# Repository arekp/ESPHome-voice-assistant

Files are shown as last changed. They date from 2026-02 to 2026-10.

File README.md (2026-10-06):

# ESPHome Voice Assistant

Asystent głosowy oparty na ESP32-S3 N16R8 z lokalnym wykrywaniem słowa budzącego dla integracji z Home Assistant.

## Opis

Ten projekt dostarcza kompletną konfigurację ESPHome do budowy asystenta głosowego używającego ESP32-S3 z lokalnym wykrywaniem słowa budzącego. System bezproblemowo integruje się z Home Assistant do sterowania inteligentnym domem.

## 🛠️ Wymagany Sprzęt
1. **ESP32-S3 DevKitC-1** (Zalecana wersja N16R8 lub N8R8)
2. **Wyświetlacz:** 1.28" Round IPS LCD (Sterownik GC9A01)
3. **Mikrofon:** INMP441 (I2S, dookólny)
4. **Wzmacniacz/DAC:** MAX98357A (I2S, 3W)
5. Głośnik: 4Ω 3W

## 🔌 Schemat Połączeń (Pinout)

### ✅ Aktualne okablowanie (zgodne z `esp_ver2.yaml`, przetestowane)

Schemat połączeń: ESP32-S3 DevKitC-1, INMP441, MAX98357A, GC9A01

| Moduł | Sygnał → GPIO | Zasilanie |
| :--- | :--- | :--- |
| Mikrofon INMP441 (sekcja 1_v5) | WS→4, SCK→5, SD→6, L/R→GND | 3V3 |
| Wzmacniacz MAX98357A (sekcja 2_1) | LRC→7, BCLK→8, DIN→18 | **3V3** (tymczasowo, patrz niżej) |
| Wyświetlacz GC9A01 (sekcja 3) | DC→9, CS→10, SDA→11, SCL→12, RES→13, BLK→14 | 3V3 |

⚠️ **Pin 5V na klonach ESP32-S3 N16R8 może nie mieć napięcia.** Obok pinu jest zworka
lutownicza **IN-OUT** – dopóki nie jest zlutowana, pin 5V nie dostaje zasilania z USB i
wzmacniacz milczy (firmware „gra”, ale nic nie słychać). Obecnie MAX98357A jest zasilany z 3V3
(działa, ciszej). Docelowo: zlutować IN-OUT i przepiąć Vin na 5V.

Pozostałe tabele poniżej to historia testowanych wariantów pinów.

Poniższa tabela przedstawia bezpieczne połączenia dla **ESP32-S3 DevKitC-1**, które nie kolidują z pamięcią Flash/PSRAM oraz wbudowanymi funkcjami.

### 1. Mikrofon (INMP441)
⚠️ Krytyczne ostrzeżenie o pinach
W układach ESP32-S3 z Octal PSRAM (N16R8), piny od GPIO 33 do GPIO 37 oraz GPIO 40, 41 i 42 są wykorzystywane wewnętrznie do komunikacji z pamięcią RAM i Flash.
| Pin INMP441 | Pin ESP32-S3 | Uwagi |
| :--- | :--- | :--- |
| **VDD** | **3.3V** | ⚠️ Podłączenie pod 5V uszkodzi mikrofon! |
| **GND** | GND | |
| **L/R** | GND | Wybór kanału Lewego |
| **WS** | GPIO 40 | Word Select |
| **SCK** | GPIO 41 | Zegar |
| **SD** | GPIO 42 | Dane wyjściowe |

### 1_v2. Mikrofon (INMP441) _V2 dla plytki ver MON16R8
| Pin INMP441 | Pin ESP32-S3 | Uwagi |
| :--- | :--- | :--- |
| **VDD** | **3.3V** | ⚠️ Podłączenie pod 5V uszkodzi mikrofon! |
| **GND** | GND | |
| **L/R** | GND | Wybór kanału Lewego |
| **WS** | GPIO 15 | Word Select |
| **SCK** | GPIO 16 | Zegar |
| **SD** | GPIO 17 | Dane wyjściowe |

### 1_v3. Mikrofon (INMP441) _V3 dla plytki ver MON16R8
Zmień piny magistrali wejściowej (mikrofonu): Piny 36 i 37 na S3 z 8MB PSRAM prawie na pewno kolidują z pamięcią. Spróbuj użyć pinów, które nie należą do zakresu 33-37.
| Pin INMP441 | Pin ESP32-S3 | Uwagi |
| :--- | :--- | :--- |
| **VDD** | **3.3V** | ⚠️ Podłączenie pod 5V uszkodzi mikrofon! |
| **GND** | GND | |
| **L/R** | GND | Wybór kanału Lewego |
| **WS** | GPIO 36 | Word Select |
| **SCK** | GPIO 37 | Zegar |
| **SD** | GPIO 39 | Dane wyjściowe |

### 1_v4. Mikrofon (INMP441) _V3 dla plytki ver MON16R8 - do opracowania 

| Pin INMP441 | Pin ESP32-S3 | Uwagi |
| :--- | :--- | :--- |
| **VDD** | **3.3V** | ⚠️ Podłączenie pod 5V uszkodzi mikrofon! |
| **GND** | GND | |
| **L/R** | GND | Wybór kanału Lewego |
| **WS** | GPIO3  | Word Select |
| **SCK** | GPIO2  | Zegar |
| **SD** | GPIO1  | Dane wyjściowe |

### 1_v5. Mikrofon (INMP441) _V3 dla plytki ver MON16R8 - do opracowania 

| Pin INMP441 | Pin ESP32-S3 | Uwagi |
| :--- | :--- | :--- |
| **VDD** | **3.3V** | ⚠️ Podłączenie pod 5V uszkodzi mikrofon! |
| **GND** | GND | |
| **L/R** | GND | Wybór kanału Lewego |
| **WS** | GPIO4  | Word Select |
| **SCK** | GPIO5  | Zegar |
| **SD** | GPIO6 | Dane wyjściowe |

----
### 2. Głośnik (MAX98357A)
| Pin MAX98357A | Pin ESP32-S3 | Uwagi |
| :--- | :--- | :--- |
| **Vin** | **5V (VBUS)** | Zalecane 5V dla lepszej jakości dźwięku |
| **GND** | GND | Wspólna masa |
| **LRC** | GPIO 4 | Word Select |
| **BCLK** | GPIO 5 | Bit Clock |
| **DIN** | GPIO 6 | Dane wejściowe |

### 2_1. Głośnik (MAX98357A)
| Pin MAX98357A | Pin ESP32-S3 | Uwagi |
| :--- | :--- | :--- |
| **Vin** | **5V (VBUS)** | Zalecane 5V dla lepszej jakości dźwięku |
| **GND** | GND | Wspólna masa |
| **LRC** | GPIO 7 | Word Select |
| **BCLK** | GPIO 8 | Bit Clock |
| **DIN** | GPIO 18 | Dane wejściowe |

### 3. Wyświetlacz (GC9A01)
| Pin GC9A01 | Pin ESP32-S3 | Funkcja |
| :--- | :--- | :--- |
| **VCC** | 3.3V | Zasilanie |
| **GND** | GND | Masa |
| **DC** | GPIO 9 | Data/Command |
| **CS** | GPIO 10 | Chip Select |
| **SDA** | GPIO 11 | SPI MOSI |
| **SCL** | GPIO 12 | SPI Clock |
| **RES** | GPIO 13 | Reset |
| **BLK** | GPIO 14 | Podświetlenie (PWM) |

---

## Konfiguracja Oprogramowania

Upewnij się, że w Twoim pliku `.yaml` sekcje `i2s_audio` i `display` korzystają z powyższych pinów.

### Dlaczego takie piny?
1.  **Piny 4-8 i 18 (Audio):** Nie kolidują z Octal PSRAM (GPIO 33-37) ani z pinami bootowania (GPIO 0, 3, 45, 46). Mikrofon i głośnik mają osobne magistrale I2S.
2.  **Piny 9-14 (SPI):** Są zgrupowane fizycznie blisko siebie na DevKicie, co ułatwia prowadzenie przewodów, i nie kolidują z pamięcią Octal SPI Flash/PSRAM (która zajmuje piny 26-32).
3.  **MAX98357A:** Ten układ automatycznie miksuje kanał lewy i prawy do mono, jeśli pin SD jest niepodłączony, co jest idealne dla prostego asystenta głosowego.

### 1. Konfiguracja Home Assistant

Zainstaluj wymagane dodatki Home Assistant:
- **Whisper** - Zamiana mowy na tekst
- **Piper** - Zamiana tekstu na mowę
- **Voice Assist** - Potok głosowy

W **Ustawienia → Asystenci głosowi** asystent używany przez urządzenie musi mieć istniejącego
agenta konwersacji (np. `OpenAI Conversation` albo `Home Assistant`), STT (Whisper) i TTS (Piper).
Nieistniejący agent powoduje natychmiastowy błąd `intent-not-supported` po słowie budzącym.

### 2. Konfiguracja ESPHome

Główny plik to `esp_ver2.yaml`. Sekrety (WiFi, klucz API, hasło OTA) trzymamy w `.env`
(wzór: `.env.example`), z którego `scripts/env2secrets.py` generuje `secrets.yaml`.

### 🚀3. Flashowanie i development

Pełna instrukcja budowy środowiska, kompilacji, wgrywania (kablem i przez WiFi) oraz
diagnostyki: **[docs/DEVELOPMENT.md](docs/DEVELOPMENT.md)**. W skrócie:

```bash
scripts/deploy.sh COM4                    # pierwszy raz kablem
scripts/deploy.sh voice-assistant.local   # potem przez WiFi
```

## Funkcje

- **Lokalne Wykrywanie Słowa Budzącego**: "Okay Nabu" przy użyciu Micro Wake Word (aktywne, gdy HA jest połączony)
- **Animowana twarz robota** (oczy-pastylki w stylu EMO/Cozmo): naturalne mruganie, rozglądanie się, płynne zmiany kształtu; pod oczami wskaźnik stanu – słupki przy słuchaniu, skaczące kropki przy myśleniu, usta przy mówieniu. Rysowane są tylko zmienione fragmenty ekranu, więc animacja nie obciąża ESP
- **Limit nasłuchu**: bez mowy przez 8 s asystent wraca do czuwania (także po pytaniu zwrotnym asystenta)
- **Wygaszacz „Matrix”**: po 3 min bezczynności zielony deszcz znaków zamiast oczu; czas ustawiasz w HA (encja „Wygaszacz Matrix po”, 0 = wyłączony), przycisk „Test wygaszacza Matrix”
- **Przyciski testowe**: Test RTTTL (dźwięk), Test wygaszacza Matrix, Wymuś Nasłuch, Restart
- **OTA Updates**: Aktualizacje oprogramowania przez sieć
- **Redukcja Szumów i auto-gain** mikrofonu

## Użycie

1. Powiedz "Okay Nabu" aby aktywować
2. Oczy robią się **zielone**, pod nimi pulsują słupki – mów polecenie
3. **Żółte**, zmrużone oczy i skaczące kropki – asystent myśli
4. **Niebieskie** oczy z ustami – asystent odpowiada z głośnika
5. Powrót do białych, mrugających i rozglądających się oczu

## Szczegóły Konfiguracji

### Ustawienia Audio
```yaml
bits_per_sample: 32bit
 sample_rate: 16000
 noise_suppression_level: 2.0
 volume_multiplier: 4.0
```

## Integracja

Asystent integruje się z encjami Home Assistant dla:
- Sterowania oświetleniem
- Sterowania przełącznikami
- Odtwarzania mediów
- Własnych skryptów

## Rozwiązywanie Problemów

### Częste Problemy
- **Brak wyjścia audio** (a w logach `rtttl: Playing song` / `i2s_audio.speaker: Starting`):
  brak napięcia na pinie 5V – zlutuj zworkę IN-OUT albo zasil MAX98357A z 3V3.
  Test: `scripts/button.py RTTTL` powinien dać dwa piknięcia.
- **Oczy nie zmieniają się po "Okay Nabu"**: sprawdź logi – jeśli jest `intent-not-supported`,
  asystent w HA ma ustawionego nieistniejącego agenta konwersacji.
- **Słowo budzące w ogóle nie działa**: wykrywanie startuje dopiero po połączeniu z Home Assistant.

Pełna lista rozwiązanych problemów: [docs/DEVELOPMENT.md](docs/DEVELOPMENT.md#7-rozwiązane-problemy-październik-2026).

### Tryb Debug
Logi przez WiFi: `esphome logs esp_ver2.yaml --device voice-assistant.local`
(albo kablem na COM4 – logger działa na `UART0`).

## Zasoby

- [Dokumentacja ESPHome](https://esphome.io/)
- [Micro Wake Word](https://github.com/kahrendt/microWakeWord)
- [Home Assistant Voice](https://www.home-assistant.io/blog/2023/12/13/year-of-the-voice-chapter-5/)
- [film prezentujacy asystenata](https://youtu.be/aDaSp6zaqWM?is=lCuZWlRpG83gZBLt)
- [Dokumentacja wyswietlacza](https://sklep.msalamon.pl/produkt/okragly-wyswietlacz-tft-ips-128-niebiesk/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)
- [kolejny przyklad implementacji](https://www.instructables.com/DIY-Pocket-Size-ESP32-AI-Voice-Assistant-With-Xiao/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)
- [Pobieranie slow wybudzenia](https://github.com/esphome/micro-wake-word-models/blob/main/models/v2/hey_jarvis.json)

## Licencja

Licencja MIT - Szczegóły w pliku LICENSE.

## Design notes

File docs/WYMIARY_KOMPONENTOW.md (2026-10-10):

# Wymiary komponentów elektronicznych

Wymiary w mm. ✅ – potwierdzone (rysunek producenta / sprzedawca), ⚠️ – przybliżone, ❌ – brak danych.

| # | Komponent | Wymiary modułu | Szczegóły | Pewność |
|---|---|---|---|---|
| 1 | **ESP32-S3 N16R8** – klon YD-ESP32-S3 (VCC-GND), 2× USB-C, CH343 | PCB **57,15 × 27,94 × 1,6**; z wystającym modułem WROOM (antena) **63,39** długości | 2 rzędy po 22 piny, raster 2,54, rozstaw rzędów **25,40**; moduł WROOM ok. 3,3 nad PCB, elementy nad PCB do ok. 4,5 | ✅ |
| 1a | Gniazda USB-C płytki | gniazdo ok. 9 × 3,2 | na krótszym brzegu (naprzeciw anteny), środki **8,1** i **19,8** mm od krawędzi płytki | ✅ |
| 2 | **Wyświetlacz okrągły 1,28" GC9A01** (msalamon) | **38 × 45,5 × 11,5** (z goldpinami) | obszar pikseli **Ø32,4**; szkło ok. Ø35,6; 8 wyprowadzeń | ✅ / szkło ⚠️ |
| 3 | **Mikrofon INMP441** (moduł I2S) | PCB ok. **14 × 14** (wersje okrągłe Ø15), gr. ok. 3 | port akustyczny – otwór w PCB | ⚠️ |
| 4 | **Wzmacniacz MAX98357A** (moduł I2S, 3 W) | **19,4 × 17,8 × 3** (klony ok. 18 × 18) | 7 pinów + złącze głośnika | ⚠️ |
| 5 | **Głośnik 4 Ω / 3 W** | ramka **63 × 63**, głębokość **12** | membrana (kosz) **Ø45** pośrodku ramki | ✅ (zmierzone) |

Wtyki dupont nałożone na goldpiny wystają ok. 14–17 mm od PCB.

## Do zmierzenia
1. Szkło wyświetlacza (średnica) i po której stronie modułu są piny.
2. Moduł INMP441: kształt (kwadrat / koło), położenie otworu akustycznego.
3. Klon MAX98357A: wymiary i czy ma złącze śrubowe głośnika.
4. Otwory montażowe modułów (średnica, położenie) – brak danych.

## Źródła
- [YD-ESP32-S3 – rysunek wymiarowy (vcc-gnd)](https://github.com/vcc-gnd/YD-ESP32-S3/tree/main/5-public-YD-ESP32-S3-Hardware%20info)
- [Wyświetlacz GC9A01 1,28" – msalamon](https://sklep.msalamon.pl/produkt/okragly-wyswietlacz-tft-ips-128-niebiesk/)
- [Waveshare 1.28inch LCD Module](https://www.waveshare.com/1.28inch-lcd-module.htm)
- [Adafruit MAX98357A](https://www.adafruit.com/product/3006)
- [INMP441 – TinyTronics](https://www.tinytronics.nl/en/sensors/sound/inmp441-mems-microphone-i2s)
- [INMP441 – datasheet (port akustyczny)](https://www.mouser.com/datasheet/2/400/INMP441-1112508.pdf)

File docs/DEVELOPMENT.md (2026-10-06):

# Środowisko developerskie

Instrukcja przygotowania komputera (Windows 11) do kompilowania, wgrywania i diagnozowania
firmware asystenta głosowego. Na Linux/macOS kroki są te same, zmieniają się tylko ścieżki
(`.venv/bin` zamiast `.venv/Scripts`, port `/dev/ttyUSB0` zamiast `COM4`).

## 1. Wymagania

| Element | Wersja / uwagi |
| :--- | :--- |
| Python | **3.12 lub nowszy** (zalecany 3.13). ESPHome 2026.9+ nie działa na 3.11 |
| ESPHome | **taka sama wersja jak dodatek ESPHome w Home Assistant** (obecnie 2026.9.1) |
| Git + Git Bash | do `scripts/deploy.sh` |
| Sterownik CH343 | gniazdo „UART” płytki widoczne jako `USB-Enhanced-SERIAL CH343 (COMx)` |
| Miejsce na dysku | ~3 GB na ESP-IDF i toolchain |

Python 3.13 bez uprawnień administratora:

```powershell
winget install --id Python.Python.3.13 --scope user
```

## 2. Środowisko Python (`.venv`)

```powershell
cd C:\Projekty\ESPHome-voice-assistant
py -3.13 -m venv .venv
.\.venv\Scripts\python.exe -m pip install --upgrade pip
.\.venv\Scripts\python.exe -m pip install -r requirements.txt
.\.venv\Scripts\esphome.exe version     # powinno pokazać 2026.9.1
```

Venv na Windows nie da się przenieść ani zmienić mu nazwy (pliki `.exe` mają zaszyte ścieżki).
Przy zmianie wersji Pythona usuń `.venv` i utwórz go od nowa.

## 3. Windows: limit długości ścieżek

ESP-IDF tworzy ścieżki dłuższe niż 260 znaków. Przy wyłączonych długich ścieżkach
(`LongPathsEnabled = 0`) kompilacja kończy się błędami typu
`fatal error: bits/c++config.h: No such file or directory` albo `WinError 206`.

Rozwiązanie bez uprawnień administratora: narzędzia ESP-IDF w krótkiej ścieżce.

```powershell
New-Item -ItemType Directory -Force C:\ESPHome\idf
[Environment]::SetEnvironmentVariable('ESPHOME_ESP_IDF_PREFIX', 'C:\ESPHome\idf', 'User')
```

(`scripts/deploy.sh` ustawia tę zmienną sam). Alternatywa: włączyć długie ścieżki w rejestrze
(PowerShell jako administrator) i zrestartować komputer:

```powershell
Set-ItemProperty 'HKLM:\SYSTEM\CurrentControlSet\Control\FileSystem' LongPathsEnabled 1
```

Projekt trzymaj w krótkiej ścieżce (np. `C:\Projekty\...`), nie w `%TEMP%` ani głęboko w profilu.

## 4. Sekrety (`.env`)

```powershell
copy .env.example .env    # i uzupełnij wartości
```

| Zmienna | Opis |
| :--- | :--- |
| `WIFI_SSID`, `WIFI_PASSWORD` | sieć WiFi |
| `FALLBACK_AP_PASSWORD` | hasło zapasowego hotspotu (min. 8 znaków) |
| `API_KEY` | klucz szyfrowania API (base64, 32 bajty) – **ten sam, co zna HA** |
| `OTA_PASSWORD` | hasło OTA – **takie jak w firmware, który jest na płytce** |
| `HA_URL`, `HA_TOKEN` | opcjonalnie: adres HA i token długoterminowy (dla `scripts/ha.py`) |

ESPHome czyta sekrety tylko z `secrets.yaml` (`!secret`), więc `scripts/env2secrets.py`
generuje go z `.env`. Robi to automatycznie `scripts/deploy.sh`; ręcznie:

```powershell
.\.venv\Scripts\python.exe scripts\env2secrets.py
```

`.env` i `secrets.yaml` są w `.gitignore` – nigdy ich nie commituj.

## 5. Kompilacja, wgrywanie, logi

Pełny cykl (walidacja → kompilacja → wgranie → 60 s logów do `logs/`):

```bash
scripts/deploy.sh COM4                      # pierwszy raz kablem (gniazdo „UART”)
scripts/deploy.sh voice-assistant.local     # kolejne razy przez WiFi (OTA)
scripts/deploy.sh voice-assistant.local 0   # bez zbierania logów
SKIP_UPLOAD=1 scripts/deploy.sh             # tylko kompilacja
```

Pojedyncze kroki (PowerShell):

```powershell
$env:PYTHONUTF8 = '1'                       # polskie znaki w konsoli Windows
.\.venv\Scripts\esphome.exe config  esp_ver2.yaml
.\.venv\Scripts\esphome.exe compile esp_ver2.yaml
.\.venv\Scripts\esphome.exe upload  esp_ver2.yaml --device voice-assistant.local
.\.venv\Scripts\esphome.exe logs    esp_ver2.yaml --device voice-assistant.local
```

- Pierwsza kompilacja pobiera ESP-IDF i toolchain (~15–25 min), kolejne trwają kilka minut.
- `esphome logs` nie kończy się sam – w skryptach używaj `timeout 60 esphome logs ...`.
- W Git Bash ESP-IDF odmawia pracy („MSys/Mingw is not supported”), bo widzi zmienną `MSYSTEM`.
  Samo `unset MSYSTEM` nie pomaga – runtime MSYS dokleja ją każdemu programowi Windows.
  `deploy.sh` uruchamia więc esphome przez Pythona, który usuwa zmienną; ręcznie najprościej z PowerShell.
- `deploy.sh` ustawia `PYTHONUNBUFFERED=1` – bez tego `timeout` ucina `esphome logs` razem z niezapisanym buforem.
- Logger działa na `UART0`, więc logi widać na COM4 (gniazdo „UART”) i przez WiFi.
- Nie da się jednocześnie wgrywać i czytać logów przez ten sam port COM.

## 6. Narzędzia diagnostyczne

```powershell
# Przyciski urządzenia przez API ESPHome (bez HA)
.\.venv\Scripts\python.exe scripts\button.py            # lista
.\.venv\Scripts\python.exe scripts\button.py RTTTL      # test głośnika (dwa piknięcia)

# Komendy WebSocket do Home Assistant (wymaga HA_URL/HA_TOKEN w .env)
.\.venv\Scripts\python.exe scripts\ha.py '{\"type\":\"assist_pipeline/pipeline/list\"}'
.\.venv\Scripts\python.exe scripts\ha.py '{\"type\":\"conversation/process\",\"text\":\"Która godzina?\",\"language\":\"pl\"}'

# Odczyt informacji o chipie przez kabel
.\.venv\Scripts\python.exe -m esptool --port COM4 flash-id
```

W logach urządzenia szukaj `[E]` i `[W]`. Przebieg poprawnej rozmowy:
`Detected 'Okay Nabu'` → `STT started` → `Speech recognised as: ...` → `Response: ...`
→ `TTS stream start` → `i2s_audio.speaker: Starting`.

## 7. Rozwiązane problemy (październik 2026)

| Objaw | Przyczyna | Rozwiązanie |
| :--- | :--- | :--- |
| YAML nie parsował się | dwie konfiguracje sklejone w jednym pliku | jedna spójna `esp_ver2.yaml`, sekrety przez `!secret` |
| Brak reakcji mikrofonu | w YAML piny 1/2/3, mikrofon podpięty do 4/5/6 | mikrofon na GPIO4/5/6 (README 1_v5) |
| Brak logów na COM4 | logger na `USB_SERIAL_JTAG`, kabel w gnieździe „UART” | `logger: hardware_uart: UART0` |
| Kompilacja: `WinError 206`, `c++config.h` | limit 260 znaków ścieżki w Windows | `ESPHOME_ESP_IDF_PREFIX=C:\ESPHome\idf` |
| Kompilacja: „MSys/Mingw is not supported” | uruchomienie z Git Bash (MSYS dokleja `MSYSTEM`) | esphome przez Pythona usuwającego zmienną / PowerShell |
| Puste logi w `deploy.sh` | `timeout` ubijał esphome przed zapisem bufora | `PYTHONUNBUFFERED=1` |
| Czarny ekran, oczy widoczne tylko w ruchu | `auto_clear_enabled` (domyślnie włączone) czyści bufor przed lambdą, a lambda pomija rysowanie bez zmian | `auto_clear_enabled: false` – lambda sama wymazuje zmienione fragmenty |
| Zrywająca się mowa, `Cannot receive audio, buffer is full` | animacja 20 kl./s blokowała pętlę główną; zmiana ust przerysowywała też oczy (duży prostokąt SPI) | oczy i usta przerysowywane osobno, 10 kl./s przy słuchaniu/mówieniu, `buffer_duration: 1000ms` |
| Asystent bez końca w trybie słuchania | HA wznawia rozmowę, gdy odpowiedź LLM kończy się pytaniem | skrypt `listen_timeout`: 8 s bez mowy → `voice_assistant.stop` |
| OTA: `connecting ... timed out` przy działającym API | zawieszona poprzednia sesja OTA | `scripts/button.py Restart` i ponowne wgranie |
| Lokalnie starsze ESPHome niż w HA | ESPHome 2026.9 wymaga Pythona ≥ 3.12 | `.venv` na Pythonie 3.13 |
| Słowo budzące „nie działa”, brak odpowiedzi | pipeline Assist „alfred” wskazywał nieistniejącego agenta `conversation.chatgpt` (HA zwracał błąd w ~20 ms, oczy mrugały na zielono niezauważalnie) | agent `conversation.openai_conversation` + „preferuj lokalne komendy” |
| Odpowiedź z innego głośnika (Atom Echo) | agent LLM użył narzędzia do wysłania komunikatu na inne urządzenie | to zachowanie LLM, nie firmware; Atom Echo odłączony |
| Cisza z głośnika (firmware odtwarza poprawnie) | pin 5V płytki bez napięcia – niezlutowana zworka **IN-OUT** na klonie N16R8 | tymczasowo Vin MAX98357A na **3V3**; docelowo zlutować IN-OUT i wrócić na 5V |

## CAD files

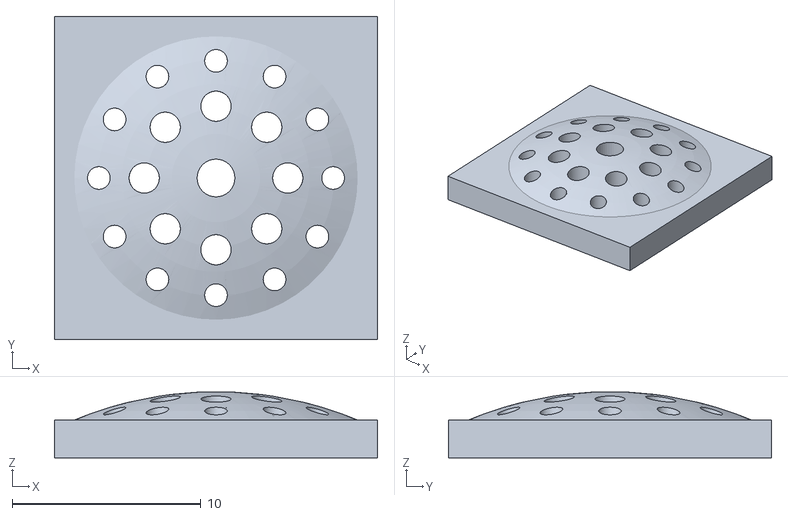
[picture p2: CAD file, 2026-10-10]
obudowa/do_druku/4_kratka_mikrofonu.stl
17.1 x 17.1 x 3.47

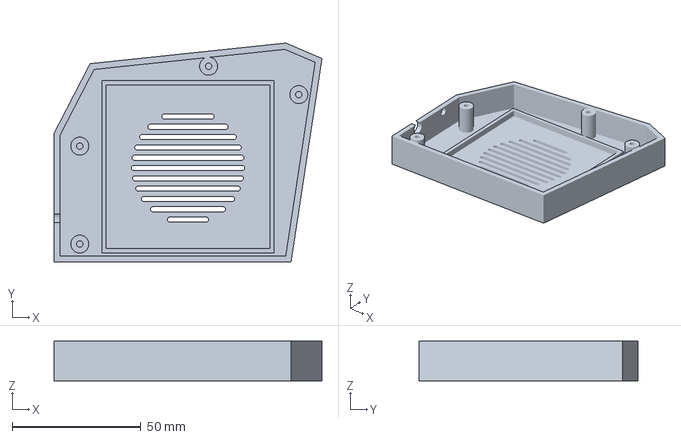
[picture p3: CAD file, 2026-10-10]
obudowa/statecznik_korpus.3mf
104.0 x 84.9 x 15.4 mm

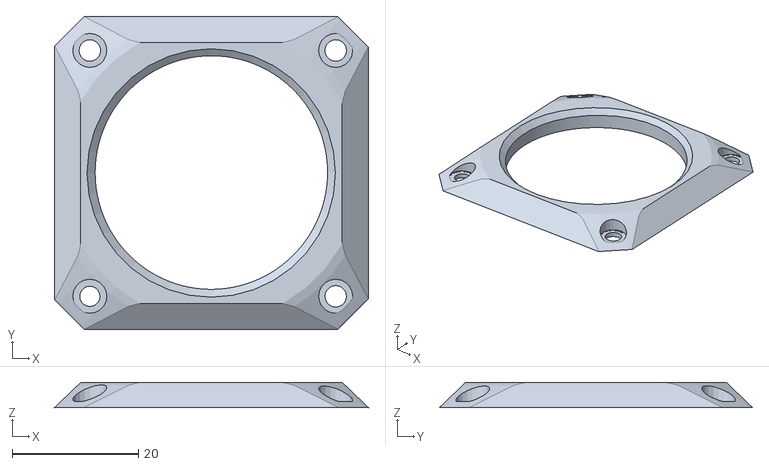
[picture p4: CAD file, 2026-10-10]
obudowa/szablon1/GC9A01_Round_OLED_Front_Contoured2.stl.stl
49.8 x 49.7 x 4.00

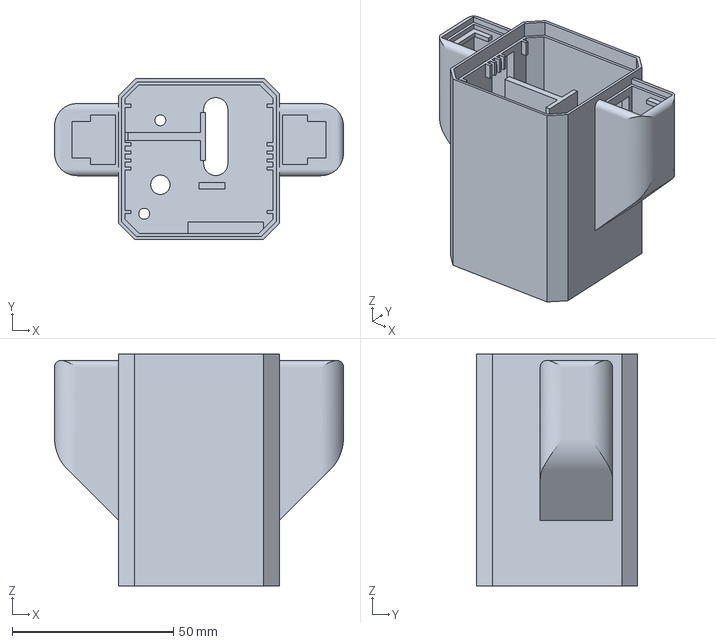
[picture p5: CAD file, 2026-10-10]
obudowa/do_druku/1_obudowa_esp32.3mf
89.7 x 49.9 x 72.0 mm

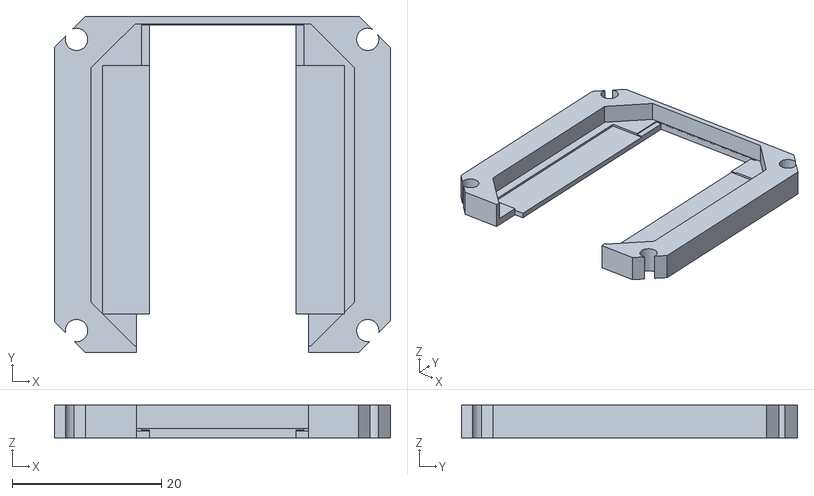
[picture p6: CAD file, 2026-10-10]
obudowa/szablon1/GC9A01_Round_OLED_Support.stl
45.0 x 45.0 x 4.40

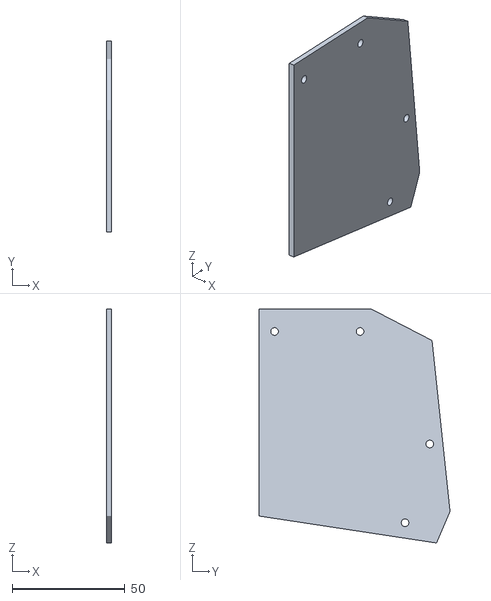
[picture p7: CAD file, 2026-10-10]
obudowa/do_druku/3_statecznik_pokrywa.stl
2.40 x 84.9 x 104.0

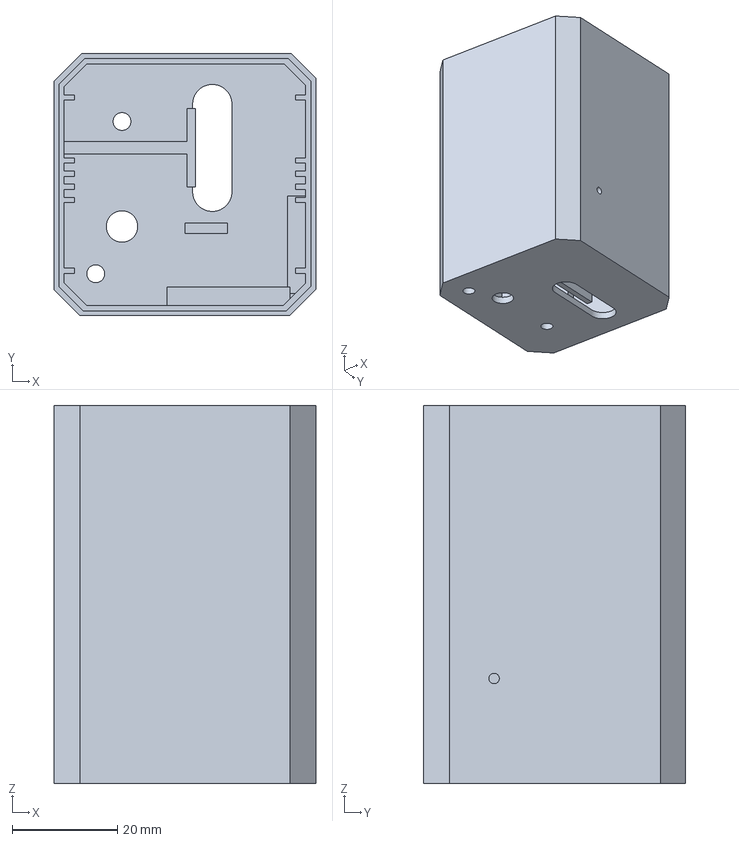
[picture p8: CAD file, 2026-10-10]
obudowa/obudowa_esp32.3mf
49.9 x 49.9 x 72.0 mm

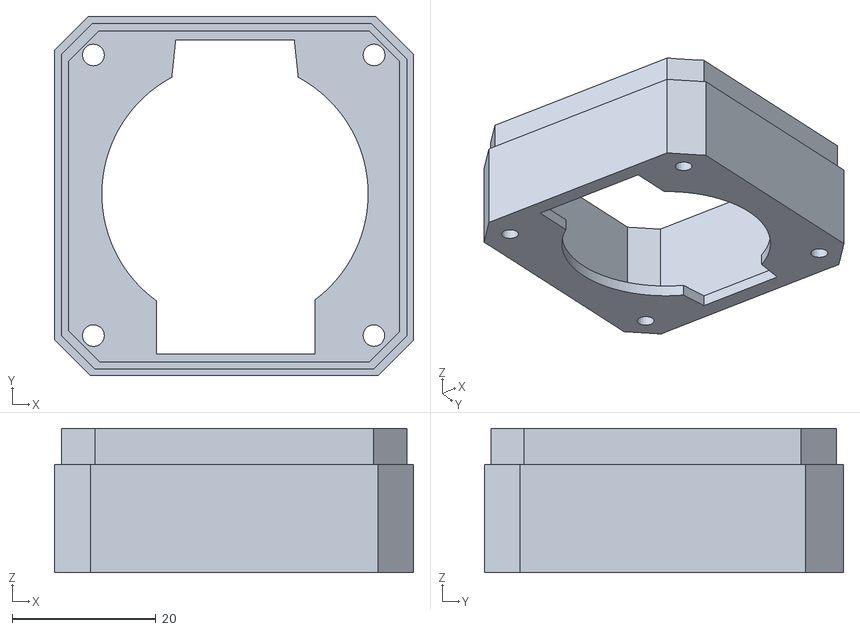
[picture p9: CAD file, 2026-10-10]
obudowa/szablon1/GC9A01_Round_OLED_Middle_notched.stl
49.9 x 49.9 x 20.0

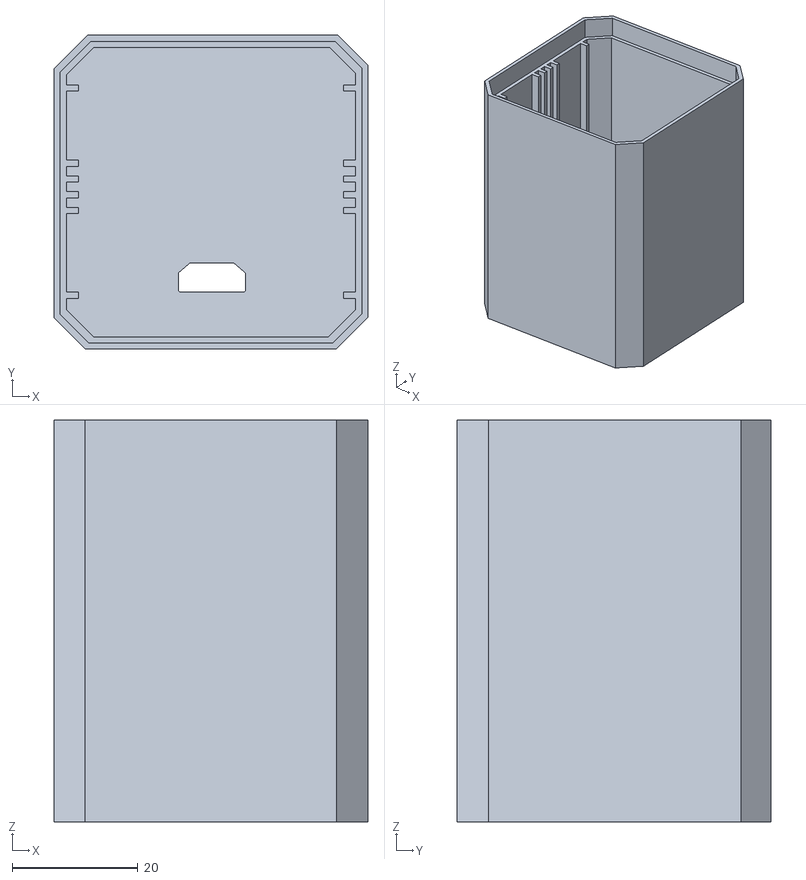
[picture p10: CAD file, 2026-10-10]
obudowa/szablon1/GC9A01_Round_OLED_Case_ribbed_usb.stl
49.9 x 49.9 x 64.0

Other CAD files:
obudowa/do_druku/2_statecznik_korpus.stl
obudowa/statecznik_pokrywa.3mf
obudowa/do_druku/1_obudowa_esp32.stl
obudowa/obudowa_esp32.stl
obudowa/statecznik_korpus.stl

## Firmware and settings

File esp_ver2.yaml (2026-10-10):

# Płytka: ESP32-S3 DevKitC-1 N16R8 (MON16R8)
# Piny zgodne z README: mikrofon sekcja 1_v5, głośnik sekcja 2_1, wyświetlacz sekcja 3.
esphome:
  name: voice-assistant
  friendly_name: voice-assistant
  on_boot:
    priority: -10
    then:
      - globals.set:
          id: va_state
          value: '0'
      # micro_wake_word startuje dopiero po połączeniu z Home Assistant
      # (voice_assistant -> on_client_connected)

esp32:
  board: esp32-s3-devkitc-1
  variant: esp32s3
  flash_size: 16MB
  framework:
    type: esp-idf
    sdkconfig_options:
      CONFIG_ESP32S3_DEFAULT_CPU_FREQ_240: y
      CONFIG_ESP32S3_DATA_CACHE_64KB: y
      CONFIG_ESP32S3_DATA_CACHE_LINE_64B: y

# Włączenie PSRAM - bez tego Wake Word nie zadziała!
psram:
  mode: octal
  speed: 80MHz

# Logi przez UART0 - płytka podłączona gniazdem "UART" (CH343, COM4)
logger:
  hardware_uart: UART0
  level: DEBUG # VERY_VERBOSE pokazuje wszystko, ale spowalnia ESP

# Enable Home Assistant API
api:
  encryption:
    key: !secret api_key

ota:
  - platform: esphome
    password: !secret ota_password

wifi:
  ssid: !secret wifi_ssid
  password: !secret wifi_password

  # Enable fallback hotspot (captive portal) in case wifi connection fails
  ap:
    ssid: "Voice-Assistant Fallback Hotspot"
    password: !secret fallback_ap_password

captive_portal:

# ---------------------------------------------------------
# STAN ASYSTENTA (Globalna zmienna dla wyświetlacza)
# 0 = Idle (Czuwanie/WakeWord), 1 = Listening (Nasłuch),
# 2 = Thinking (Przetwarzanie), 3 = Speaking (Mówienie)
# ---------------------------------------------------------
globals:
  - id: va_state
    type: int
    restore_value: no
    initial_value: '0'

  # Wygaszacz "Matrix": ostatnia aktywność asystenta (millis) i wymuszenie z przycisku
  - id: last_active_ms
    type: uint32_t
    restore_value: no
    initial_value: '0'
  - id: matrix_force
    type: bool
    restore_value: no
    initial_value: 'false'

# Bez mowy przez 8 s od otwarcia mikrofonu (np. po pytaniu zwrotnym asystenta,
# gdy HA sam wznawia rozmowę) - przerwij nasłuch i wróć do czuwania
script:
  - id: listen_timeout
    mode: restart
    then:
      - delay: 8s
      - if:
          condition:
            lambda: 'return id(va_state) == 1;'
          then:
            - logger.log: "Brak mowy przez 8 s - koniec nasłuchu"
            - voice_assistant.stop:

# Po ilu sekundach bezczynności włączyć wygaszacz (0 = nigdy) - ustawiane z HA
number:
  - platform: template
    name: "Wygaszacz Matrix po"
    id: matrix_timeout
    icon: mdi:matrix
    entity_category: config
    unit_of_measurement: s
    mode: box
    min_value: 0
    max_value: 3600
    step: 30
    initial_value: 180
    optimistic: true
    restore_value: true

# ---------------------------------------------------------
# KONFIGURACJA AUDIO (I2S)
# ---------------------------------------------------------
i2s_audio:
  # Magistrala Mikrofonu (Input)
  - id: i2s_in
    i2s_lrclk_pin: GPIO4
    i2s_bclk_pin: GPIO5

  # Magistrala Głośnika (Output)
  - id: i2s_out
    i2s_lrclk_pin: GPIO7
    i2s_bclk_pin: GPIO8

microphone:
  - platform: i2s_audio
    id: board_microphone
    i2s_audio_id: i2s_in
    i2s_din_pin: GPIO6
    adc_type: external
    pdm: false
    channel: left # INMP441 (L/R zwarty do GND)
    bits_per_sample: 32bit
    sample_rate: 16000

speaker:
  - platform: i2s_audio
    id: board_speaker
    i2s_audio_id: i2s_out
    i2s_dout_pin: GPIO18
    dac_type: external
    channel: mono
    bits_per_sample: 16bit
    buffer_duration: 1000ms   # zapas na chwilowe opóźnienia pętli głównej
    timeout: 500ms

# ---------------------------------
# Przyciski testowe / debug
# ---------------------------------
rtttl:
  speaker: board_speaker
  id: my_rtttl
  gain: 0.8

button:
  - platform: template
    name: "Test RTTTL (Prawdziwy dźwięk)"
    on_press:
      - rtttl.play: "TwoBeeps:d=4,o=5,b=100:16e6,16e6"

  - platform: template
    name: "Wymuś Nasłuch (Debug)"
    on_press:
      - voice_assistant.start:

  - platform: template
    name: "Test wygaszacza Matrix"
    on_press:
      - globals.set:
          id: matrix_force
          value: 'true'

  - platform: restart
    name: "Restart"

# ---------------------------------------------------------
# LOGIKA ASYSTENTA GŁOSOWEGO I WAKE WORD
# ---------------------------------------------------------
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

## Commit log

2026-02-21 Add ESPHome voice assistant configuration
    - ESP32-S3 voice assistant with INMP441 microphone
    - MAX98357A audio amplifier
    - WS2812 LED bar (8 LEDs)
    - Micro Wake Word with 'hey_jarvis'
    - Home Assistant integration
2026-02-21 Update README with comprehensive project description
    - Add detailed hardware requirements
    - Include circuit diagram
    - Document software setup steps
    - Describe features and usage
    - Add troubleshooting section
    - Include resource links
2026-02-24 poinout esp32-s3
2026-02-24 Revise hardware requirements and connection details
    Updated hardware requirements and connection diagrams for ESP32-S3 project.
2026-02-24 Fix pin assignments for components in README
2026-02-24 Add variant specification for ESP32 board
2026-02-25 Update README with pin warnings and new microphone info
    Added critical warning about pin usage for ESP32-S3 with Octal PSRAM and updated microphone connection details for board version MON16R8.
2026-02-25 Revise INMP441 microphone sections in README
    Updated microphone sections for INMP441 to include versioning and pin recommendations.
2026-02-25 Update README for ESP32-S3 model specification
2026-02-26 Document INMP441 microphone pin connections
    Added section for INMP441 microphone pin connections.
2026-02-26 Revise GPIO pin assignments in README
    Updated GPIO pin assignments for microphone and speaker connections in the README.
2026-02-27 Configure ESP32 voice assistant with audio features
    Added configuration for ESP32 voice assistant with wake word detection and audio processing.
2026-10-05 Napraw konfigurację ESPHome i dodaj cykl deploy z logami
    - esp_ver2.yaml: jedna spójna konfiguracja (wcześniej dwie sklejone,
    YAML nie parsował się), sekrety przez !secret, start wake word po
    połączeniu z HA, timeout w on_end, usunięte use_wake_word i opcje
    Arduino, model okay_nabu z GitHuba, polskie znaki w czcionce
    - scripts/deploy.sh: walidacja, kompilacja, wgranie, logi do logs/
    - secrets.yaml.example, .gitignore dla ESPHome
    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
2026-10-06 Uruchom asystenta na płytce: piny, środowisko dev i dokumentacja
    Firmware przetestowany na ESP32-S3 N16R8: słowo budzące, STT, odpowiedź
    LLM i odtwarzanie TTS działają end-to-end.
    - esp_ver2.yaml: mikrofon na GPIO4/5/6 (faktyczne okablowanie, README 1_v5),
    logger na UART0 (płytka podłączona gniazdem UART, CH343/COM4)
    - sekrety w .env (.env.example), scripts/env2secrets.py generuje secrets.yaml
    - scripts/deploy.sh: używa .venv, PYTHONUTF8, unset MSYSTEM i krótkiej
    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
2026-10-06 Dodaj schemat połączeń (SVG) do README
    docs/schemat-polaczen.svg: piny lewego złącza DevKitC-1 w fizycznej
    kolejności, przewody INMP441, MAX98357A i GC9A01 kolorami wg funkcji,
    zworka IN-OUT i docelowe 5V dla wzmacniacza. Jasny i ciemny motyw.
2026-10-06 Dodaj wygaszacz Matrix, sensory kosztów OpenAI i popraw deploy.sh
    - esp_ver2.yaml: wygaszacz "Matrix" (zielony deszcz znaków) po bezczynności
    zamiast oczu; czas ustawiany z HA (number "Wygaszacz Matrix po", 0 = off),
    przycisk "Test wygaszacza Matrix", czcionka Share Tech Mono
    - homeassistant/openai_koszty.yaml: pakiet HA z sensorami REST - koszt USD
    i tokeny OpenAI (miesiąc/dzisiaj) z Admin API
    - scripts/deploy.sh: esphome przez Pythona usuwającego MSYSTEM (Git Bash
    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
2026-10-10 Dodaj obudowę do druku 3D (Fusion 360) z dwiema gondolami mikrofonu
    Skrypt obudowa/obudowa_esp32.py buduje obudowę na bazie szablonu
    GC9A01 Round OLED Case (Thingiverse 6110473, CC BY): skrzynka pod
    ESP32-S3, gondole INMP441 na obu bokach z wciskanymi kratkami, ramka
    MAX98357A i statecznik z głośnikiem. Pliki do druku w obudowa/do_druku,
    wymiary modułów w docs/WYMIARY_KOMPONENTOW.md.
    [1_obudowa_esp32.3mf, 1_obudowa_esp32.stl, 2_statecznik_korpus.stl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]
